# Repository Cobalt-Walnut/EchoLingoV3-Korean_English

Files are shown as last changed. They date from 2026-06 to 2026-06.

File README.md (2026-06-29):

# EchoLingoV3-Korean_English
The code was finalized on 29 Jun, 2026 by reconstructing snippets of code that is on a plane to South Korea
for the FIRST LEGO League Korea Open Invitational with FLL team 66538 - TheVikings TempleTech :D

# Details
EchoLingo is a bidirectional English to Korean translation program (and many more languages are possible) that is running on a Raspberry Pi 5
with a MAX98357A amp, a 3ohm 5w speaker, a USB mic, 2 buttons, 2 LEDs, and a SPDT toggle switch. The case is 
custom and can be found on GitHub at github.com/Cobalt-Walnut/EchoLingoV3-Korean_English/CAD

# Check out my website for EchoLingo's development process
https://cobalt-walnut.github.io/projects/offline-translator.html

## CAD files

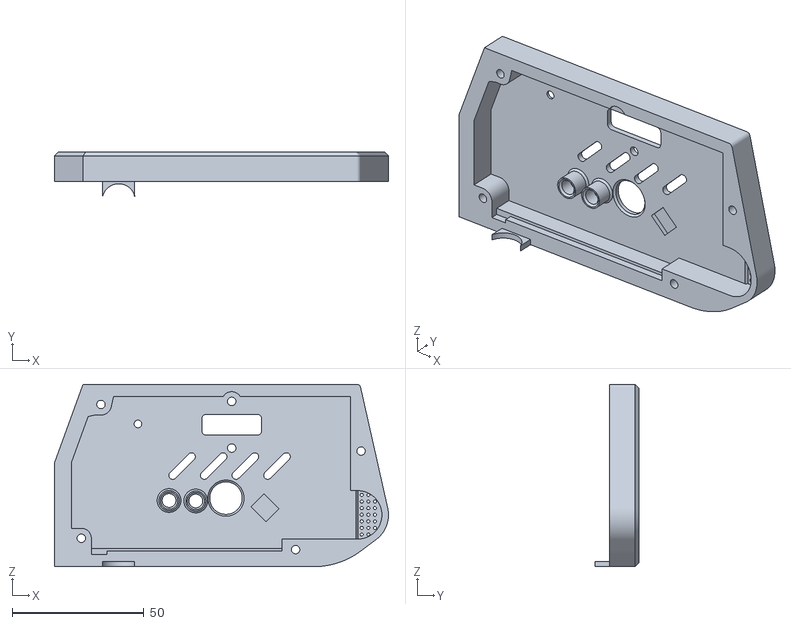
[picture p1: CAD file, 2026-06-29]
CAD/Echolingo V3 - Cover.stl
126.6 x 16.8 x 69.2

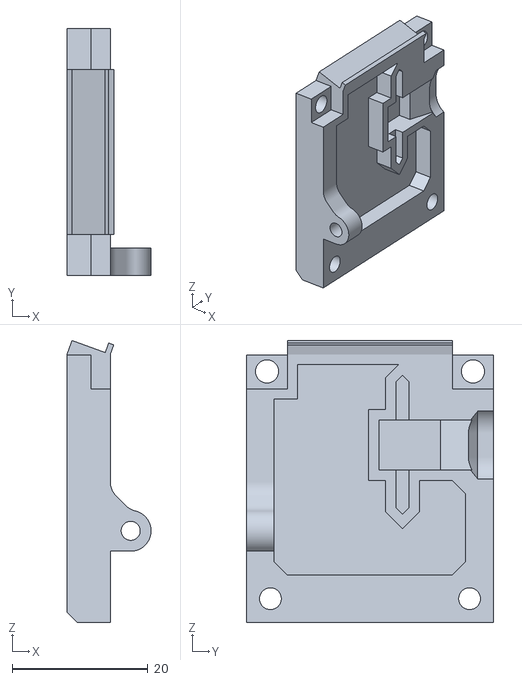
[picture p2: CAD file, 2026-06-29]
CAD/Echolingo V3 - Amp Panel.stl
12.4 x 36.3 x 41.5

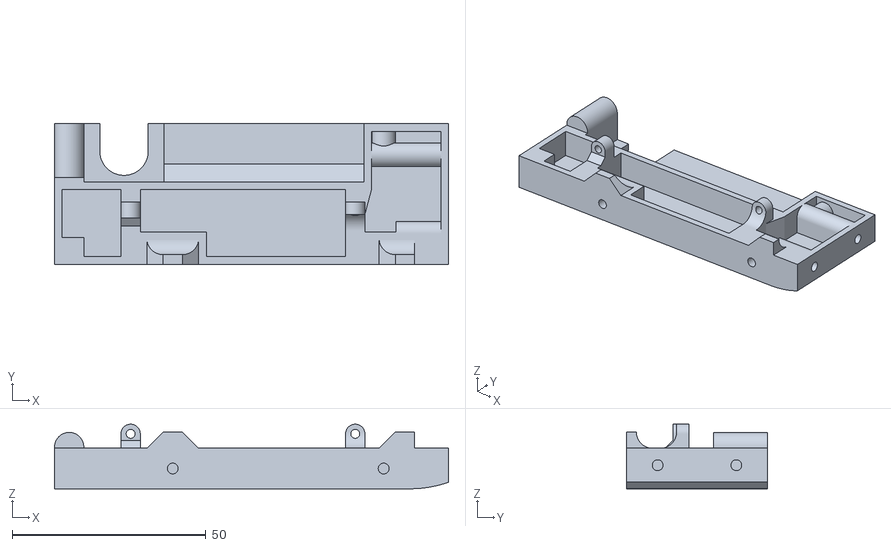
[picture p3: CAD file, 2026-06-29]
CAD/Echolingo V3 - Button Side Panel.stl
101.8 x 36.3 x 16.7

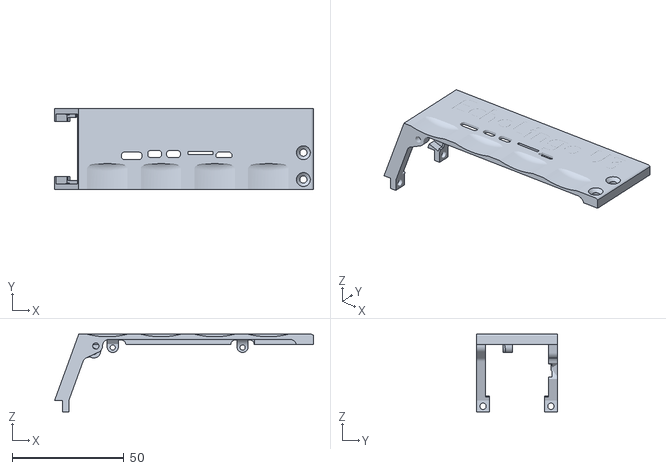
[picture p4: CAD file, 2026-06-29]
CAD/Echolingo V3 - Pisugar Side Panel.stl
115.8 x 36.3 x 34.7

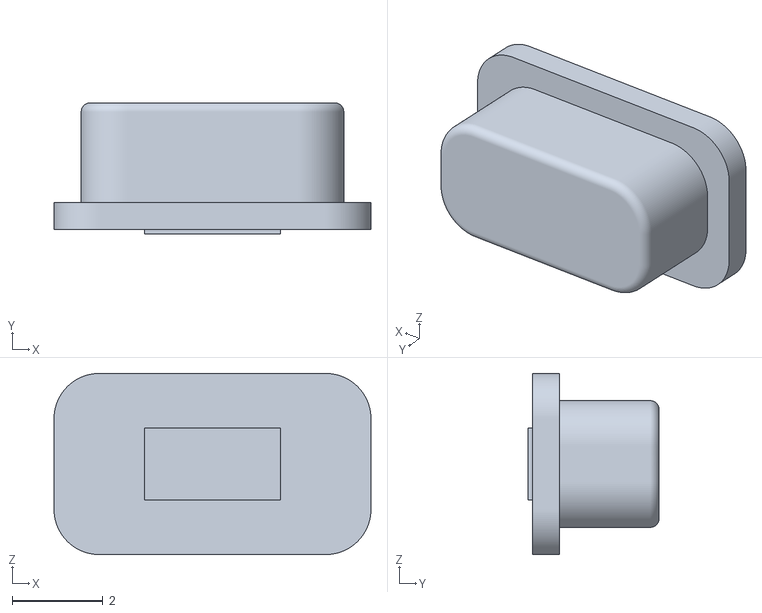
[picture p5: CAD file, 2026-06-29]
CAD/Pi Sugar button.stl
7.00 x 2.90 x 4.00

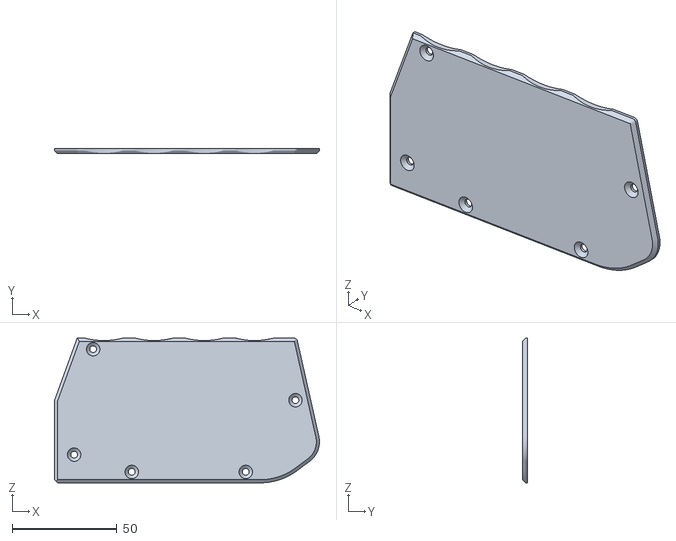
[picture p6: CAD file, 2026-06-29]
CAD/Echolingo V3 - Bottom.stl
126.6 x 2.60 x 69.2

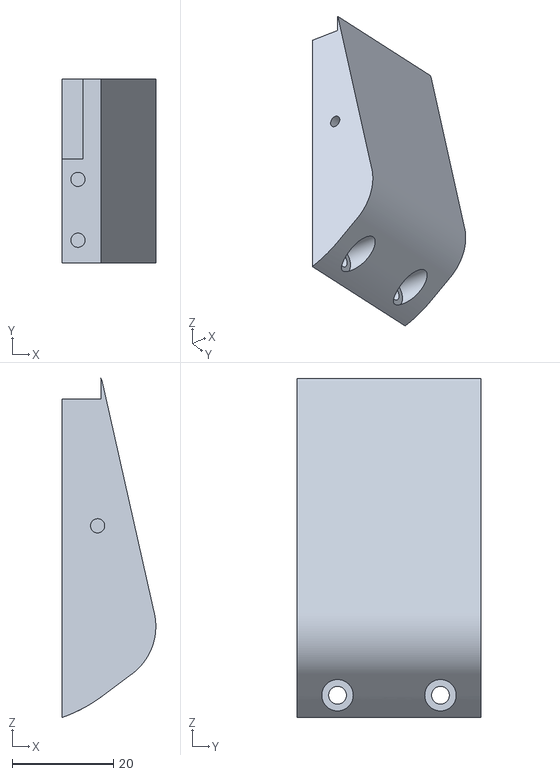
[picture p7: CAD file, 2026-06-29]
CAD/Echolingo V3 - Mic Panel.stl
18.5 x 36.3 x 66.9

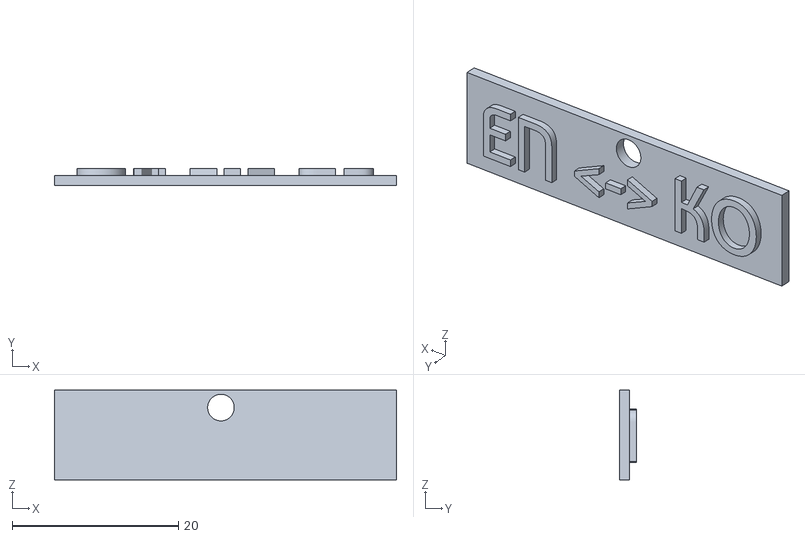
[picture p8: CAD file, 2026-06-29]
CAD/Echolingo V3 - EN-KO Lang-Label.stl
41.2 x 2.00 x 10.8

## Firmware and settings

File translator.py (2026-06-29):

'''
This code was finalized on 29 Jun, 2026 by reconstructing snippets of code that is on a plane to South Korea
for the FIRST LEGO League Korea Open Invitational with FLL team 66538 - TheVikings TempleTech :D

It's a bidirectional English to Korean (and vice versa) translation program that is running on a Raspberry Pi 5
with a MAX98357A amp, a 3ohm 5w speaker, a USB mic, 2 buttons, 2 LEDs, and a SPDT toggle switch. The case is 
custom and can be found on GitHub at github.com/Cobalt-Walnut/EchoLingoV3-Korean_English/CAD
'''

from gpiozero import LED, Button, DigitalInputDevice
import time
import queue
import numpy as np
import sounddevice as sd
import soundfile as sf
import subprocess
import os
import sys
import re
import tempfile
import threading
import torch
from transformers import (
    AutoModelForSeq2SeqLM,
    AutoTokenizer,
    VitsModel,
)

# ---------------------------------------------------------------------------
# Audio Devices
# ---------------------------------------------------------------------------
APLAY_DEVICE = "plughw:MAX98357A"
INPUT_DEVICE_NAME = "USB PnP Sound Device"        # USB Mic (PnP Sound Device)
RECORD_RATE  = 44100    # native USB mic rate
WHISPER_RATE = 16000    # whisper requires 16000Hz
SAMPLE_RATE  = WHISPER_RATE

# ---------------------------------------------------------------------------
# GPIO
# ---------------------------------------------------------------------------
RED_LED_PIN   = 22
GREEN_LED_PIN = 27
BUTTON_PIN    = 4
SWITCH_PIN    = 13
EXIT_BTN_PIN  = 5

red_led          = LED(RED_LED_PIN)
green_led        = LED(GREEN_LED_PIN)
record_button    = Button(BUTTON_PIN,    pull_up=True)
direction_switch = DigitalInputDevice(SWITCH_PIN, pull_up=False)
exit_button      = Button(EXIT_BTN_PIN, pull_up=True, bounce_time=0.1)

# ---------------------------------------------------------------------------
# Paths
# ---------------------------------------------------------------------------
WHISPER_BIN   = os.path.expanduser("~/whisper.cpp/build/bin/whisper-cli")
WHISPER_MODEL = os.path.expanduser("~/whisper.cpp/models/ggml-base.bin")
PIPER_BIN     = "/home/echolingo/translator-env/bin/piper"
PIPER_MODEL   = os.path.expanduser("~/piper_models/en_US-ryan-high.onnx")
PIPER_CONFIG  = os.path.expanduser("~/piper_models/en_US-ryan-high.onnx.json")
SOUNDS_DIR    = os.path.expanduser("~/sounds")
PISUGAR_SOCKET = "/tmp/pisugar-server.sock"

# Sound files
SND_STARTUP          = os.path.join(SOUNDS_DIR, "startup.wav")
SND_MODE_KO_EN       = os.path.join(SOUNDS_DIR, "mode_ko_en.wav")
SND_MODE_EN_KO       = os.path.join(SOUNDS_DIR, "mode_en_ko.wav")
SND_NO_SPEECH        = os.path.join(SOUNDS_DIR, "no_speech.wav")
SND_GOODBYE          = os.path.join(SOUNDS_DIR, "goodbye.wav")
SND_BATTERY_30       = os.path.join(SOUNDS_DIR, "battery_30.wav")
SND_BATTERY_25       = os.path.join(SOUNDS_DIR, "battery_25.wav")
SND_BATTERY_20       = os.path.join(SOUNDS_DIR, "battery_20.wav")
SND_BATTERY_CRITICAL = os.path.join(SOUNDS_DIR, "battery_critical.wav")
SND_STARTUP_BLIP     = os.path.join(SOUNDS_DIR, "startup_blip.wav")
SND_BLIP             = os.path.join(SOUNDS_DIR, "blip.wav")

# ---------------------------------------------------------------------------
# Protected competition terms
# ---------------------------------------------------------------------------
PROTECTED_TERMS = [
    "FIRST LEGO League",
    "SPIKE Prime",
    "SPIKE",
    "EV3",
    "FLL",
    "FIRST",
    "LEGO",
]

WHISPER_PROMPT = (
    "FIRST LEGO League, FLL, FIRST, LEGO, EV3, SPIKE, SPIKE Prime, "
    "Robot Game, Innovation Project, Core Values"
)
# ---------------------------------------------------------------------------
# TTS settings
# ---------------------------------------------------------------------------
TTS_VOLUME        = "0.70"
PIPER_SPEED       = "1.4"   # length_scale: >1.0 = slower, <1.0 = faster
MMS_SPEAKING_RATE = 0.6    # <1.0 = slower for MMS-TTS

# ---------------------------------------------------------------------------
# Exit flag
# ---------------------------------------------------------------------------
exit_requested = False

# ---------------------------------------------------------------------------
# Battery warning state
# ---------------------------------------------------------------------------
battery_warnings_fired = set()

# ---------------------------------------------------------------------------
# Helpers
# ---------------------------------------------------------------------------
def get_input_device():
    for i, dev in enumerate(sd.query_devices()):
        if (
            INPUT_DEVICE_NAME.lower() in dev["name"].lower()
            and dev["max_input_channels"] > 0
        ):
            return i

    raise RuntimeError(
        f"Could not find input device: {INPUT_DEVICE_NAME}"
    )
    
def play(path):
    if os.path.exists(path):
        subprocess.run(["aplay", "-D", APLAY_DEVICE, path])
    else:
        print(f"[WARN] Sound file missing: {path}")

def play_tts_wav(tmp_wav):
    reduced = tmp_wav + ".reduced.wav"
    subprocess.run(["sox", tmp_wav, reduced, "vol", TTS_VOLUME], check=True)
    subprocess.run(["aplay", "-D", APLAY_DEVICE, reduced])
    os.unlink(reduced)

def get_direction():
    return "ko_to_en" if direction_switch.value == 1 else "en_to_ko"

def direction_label(d):
    return "KO->EN" if d == "ko_to_en" else "EN->KO"

# ---------------------------------------------------------------------------
# Exit handler
# ---------------------------------------------------------------------------
def exit_program():
    global exit_requested
    print("\nExit button pressed.")
    for _ in range(8):
        red_led.toggle()
        time.sleep(0.25)
    red_led.off()
    green_led.off()
    play(SND_GOODBYE)
    exit_requested = True

exit_button.when_pressed = exit_program

# ---------------------------------------------------------------------------
# PiSugar 3 Plus — battery via Unix socket
# ---------------------------------------------------------------------------
def get_battery_level():
    if not os.path.exists(PISUGAR_SOCKET):
        return None
    try:
        result = subprocess.run(
            ["nc", "-q", "0", "-U", PISUGAR_SOCKET],
            input="get battery",
            capture_output=True,
            text=True,
            timeout=3
        )
        for line in result.stdout.splitlines():
            if line.startswith("battery:"):
                return int(float(line.split(":")[1].strip()))
    except Exception as e:
        print(f"[WARN] Battery read failed: {e}")
    return None
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

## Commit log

2026-06-29 Update audio settings and enhance translation process
    Refactor audio device settings, add battery monitoring, and improve translation flow.
2026-06-29 added STLs for the case
    [Echolingo V3 - Amp Panel.stl, Echolingo V3 - Bottom.stl, Echolingo V3 - Button Side Panel.stl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]
